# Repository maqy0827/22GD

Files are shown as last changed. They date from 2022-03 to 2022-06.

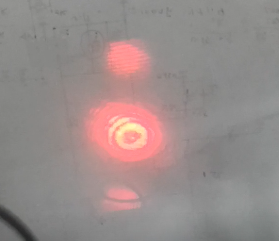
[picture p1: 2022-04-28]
Book/Image/干涉条纹实物图.png

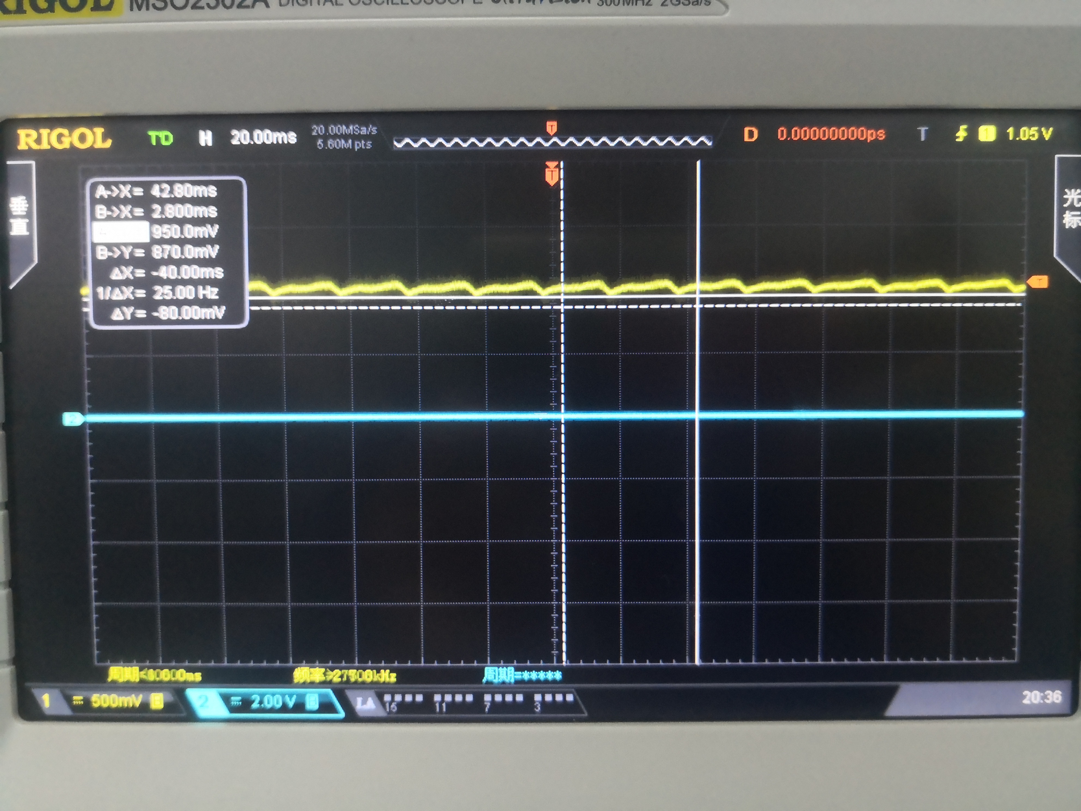
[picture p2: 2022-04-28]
Book/Image/激光光源.jpg

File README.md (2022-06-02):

# 诗云

本项目是来自哈工大威海校区某弱鸡的毕业设计，题目为`基于迈克尔逊干涉仪的位移测量系统`。如希望了解该毕设可以参考[迈克尔逊干涉仪调节实验](https://www.bilibili.com/video/BV1gW411y7Xq)。

# 详细介绍

如果你想看最详细的介绍，我推荐直接看[毕业设计论文](/Book/Thesis/Thesis.pdf)。在写论文的过程中拍摄了实验现象的视频，如有需要可以联系我(邮箱15876781@qq.com，应该不会有吧hhhh)

## 硬件与软件

如果你想复现此项目，你需要准备如下硬件与软件

> 软件
>
> - 绘制电路板使用`Altium Designer 22`
> - 程序设计使用`Keil_v5 (MDK536)`
> - 毕业论文书写~~Texlive2021~~`Word`
> - 推荐使用`VScode`阅读本项目

> 硬件（实物
>
> - 搭建迈克尔逊干涉仪所需的全部光学组件
>> - He-Ne 激光器一个（或其他激光器，但不要使用半导体激光器
>> - 扩束镜一个（或凸透镜 / 凹透镜等可以扩束的光学仪器）
>> - 50/50 分光棱镜（分光片也行但不推荐）
>> - 反光镜两个（均配合二维调整架使用）
>> - 最好有一个光学平台
> - 电路部分所需概要（详情查看原理图 / BOM 表
>> - STM32F103CxT6 最小系统板一块
>> - 12864 OLED 0.96寸 IIC通信 显示屏一块
>> - USB 转串口一个
>> - 电路板所需的其他元器件（包括运放，阻容，光电传感器

## 文件夹

- `.vscode` VScode 配置文件
- `Book` 中期报告与论文
  - `Image` README 与实验记录图片/视频
  - `Midterm` 中期报告
  - `Open` 开题报告
  - `Thesis` 毕业论文与数据处理
- `PCB` 电路板与原理图
  - `Libraries` 原理图库和元件库
  - `22GD` 毕设使用电路板
  - `Test1` 首次测试使用电路板
- `Project` 单片机程序
  - `MDK` **MDK工程入口**
  - 其余文件夹均为程序库

# 感谢

> 感谢以下项目作者
>
> - [dustincys/hithesis: 嗨！thesis！哈尔滨工业大学毕业论文LaTeX模板 (github.com)](https://github.com/dustincys/hithesis)

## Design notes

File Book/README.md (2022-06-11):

# 论文

~~因为 word 对公式的支持实在不咋样，因此毕业论文决定使用`Latex`书写。而从零开始使用`Latex`书写论文有点麻烦（还不如用word）因此，在思考过后决定使用[Dustin](https://github.com/dustincys)大佬完成的哈尔滨工业大学论文开源模板[Hithesis](https://github.com/dustincys/hithesis)（均为`github`网站，如果访问有困难请前往`Gitee`）~~
被老师gank，不能用Latex，老实点用word吧，想办法把word加入git好了

## 开题报告

开题报告于 2021 年 12 月 31 日进行。该报告文件均位于`Open`文件夹中。包含开题报告word版，开题报告pdf版，开题报告使用到的流程图 与 开题报告PPT

## 中期报告

中期报告于 2022 年 4 月 29 日进行，需要完成 70 % 的工作内容和纸质中期报告。该报告所需文件均位于`Minterm`文件夹中。

## 毕业论文

毕业论文于 2022 年 6 月 2 日完成，该报告文件均位于`Thesis`文件夹中， 文件夹内容如下

- `main.m` 处理数据，分析误差
- `Thesis.docx` 毕业论文word版
- `Thesis.vsdx` 论文中使用的框图
- `Thesis.pptx` 验收使用的ppt
- `答辩.pptx` 答辩使用的ppt
- `Liu_2021_J._Phys.__Conf._Ser._2112_012015.pdf` 待翻译的英文文献
- `英文文献翻译.docx` 翻译后的英文文献
- `知网查重报告.pdf` 终稿论文查重报告

验收时PPT内容不怎么重要，你只要保证你ppt，你的毕设内容完整，最好拍一个视频。比如我验收时ppt直接跳过了前边几乎所有，直奔视频了。几乎两三分钟就可以验完一个人，只要做的东西不水就完全没有问题。

- [X] 修改缩进
- [X] 重新画图
- [X] 电阻统一
- [X] 表格字体
- [X] 流程图线粗
- [X] 单位分号
- [X] 结论分号

## 装袋

- [ ] 信息学院本科毕设过程管理记录表
- [ ] 装订好的论文
- [X] 开题报告
- [X] 中期报告
- [ ] 中英译文
- [ ] 指导老师签字的日志

# 数据分析

实验数据分析使用`MATLAB`软件，通过给压电陶瓷加已知电压产生待测位移，在[该网站](http://www.pantpiezo.com/product/3.html)可以找到压电陶瓷的参数 5um/150V，即 33 nm/V，由此可获得位移真值用于和实验结果对比。

# 感谢

> 感谢以下项目作者
>
> - [dustincys/hithesis: 嗨！thesis！哈尔滨工业大学毕业论文LaTeX模板 (github.com)](https://github.com/dustincys/hithesis)

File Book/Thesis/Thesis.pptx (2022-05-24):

## 基于迈克尔逊干涉仪的 位移测量系统

指导老师：任秀云
180220214
马清源

## 研究内容

本毕业设计旨在构造一台通过迈克尔逊干涉仪实现的位移测量系统。
右图为设计的光路图和信号处理流程图。最终的设计目的是能以较高的精度测量输入的位移（理论精度为±λ/8）

## 信号处理框图

## 光电传感器与放大电路

- 光电传感器选择了SFH203P型号光电二极管，右图为放大电路

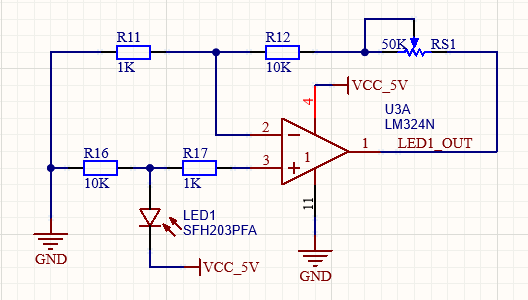
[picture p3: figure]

## 整形电路

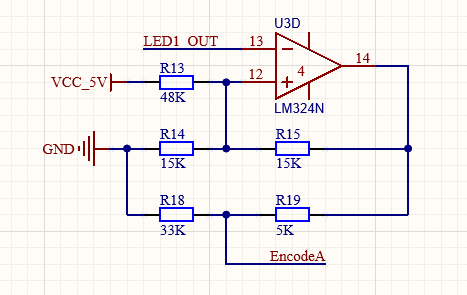
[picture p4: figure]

- 为了计数需要将波形转化为方波，右图为滞回比较器电路图

## 放大和整形电路仿真

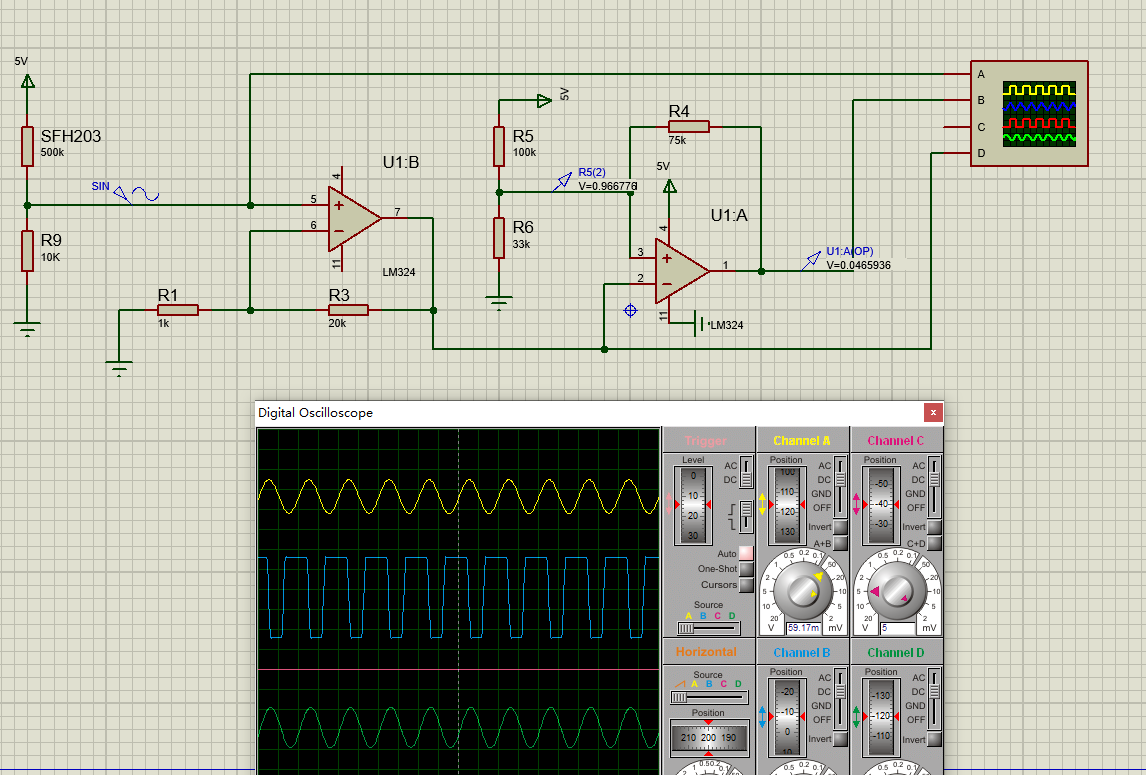
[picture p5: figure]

## 编码器计数原理

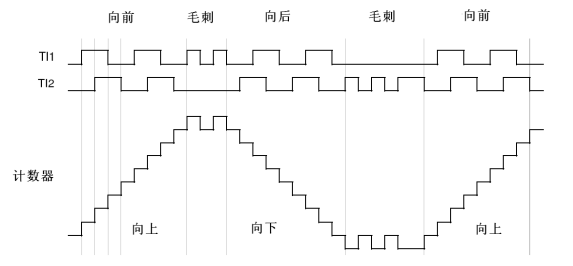
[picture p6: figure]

## 结论和成果展示

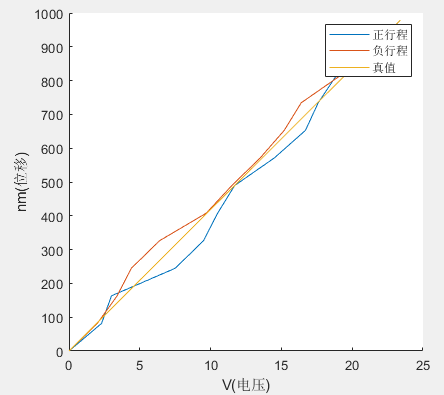
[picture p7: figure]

- 如右图是某一次测量中记录的数据。
- 在多次采集后对误差进行分析可以得到（？）

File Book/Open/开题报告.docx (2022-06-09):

毕业设计（论文）开题报告

题 目： 基于迈克尔逊干涉仪的位移

测量系统

专 业 测控技术与仪器

学 生 马清源

学 号 180220214

班 号 1802202

指导教师 任秀云

日 期 2021/12/29

1．课题背景及研究的目的和意义

科学研究的不断深入，众多领域已步入了微纳米级空间的探索，微位移的测量科学研究的不断深入，众多领域已步入了纳米级空间的探索，位移的测量精度越来越受到重视。无论是航空、航天、大飞机、高铁等大国重器的生产制造，还是芯片、通信光纤、高端医疗设备等民生产品的加工制造，往往都依赖于位移检测的精度，检测精度的高低在优化生产流程、提高产品质量的过程中发挥了至关重要的作用。

高精度的位移测量系统作为机械、仪表、宇航、兵器、工具等产业获得位置高精度的基础，同时也是影响上述产业产品和技术不断进步的制约因素之一。特别是在军事领域，各项武器、仪表等的制作对精度要求极高，因此，拥有高精度的微位移测量技术显得至关重要。在高精度位移测量方面，光干涉计量以其能够精确到波长级的测量优势成为位移测量系统的主要代表。

迈克尔逊干涉仪有着广泛的应用，例如气体折射率测量仪，如图1-1，和液体折射率测量仪，如图1-2。该装置就利用了迈克尔逊干涉仪的原理。

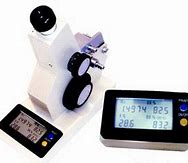
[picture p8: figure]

图1-1 空气折射率测量仪

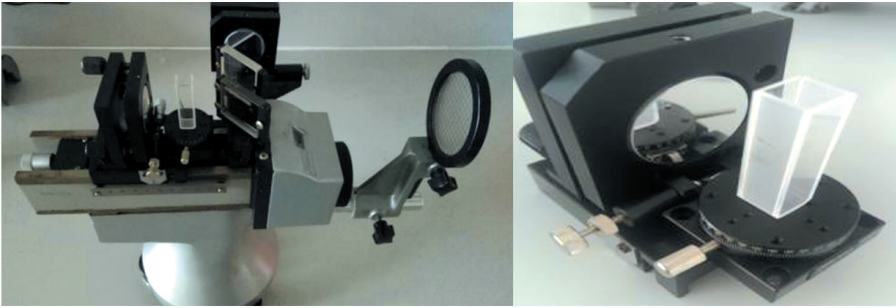
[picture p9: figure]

图1-2 液体折射率测量仪

除此之外，迈克尔逊干涉仪还能用来测量位移量和震动，测量角度或薄透明体的厚度和折射率，测量气体浓度等。迈克尔逊干涉仪的诸多改良也有广泛的用途，例如光纤迈克尔逊干涉仪能够测量混凝土内部应变和地震波加速度。可知迈克尔逊干涉仪的应用非常广泛。

2．国内外在该方向的研究现状及分析

到现在为止，按照测量转换方式的差异，可以将位移测量技术分为，机械测量法，光学测量发和电学测量法。相较于机械测量易受工作环境影响，虽然光学测量法价格较高，但是光学测量法拥有较高的测量精度。下面按照技术路线介绍国内外在微位移测量方面的研究现状和分析。

（1）机械测量技术以扫描探针显微镜为代表，同时也涵盖了机械探针式，根据物体与探针接触方式的不同可将其分为光子扫描隧道显微镜、扫描隧道显微镜、扫描近场光学显微镜和原子力显微镜等几种类型。显微测量技术大都具有很高的精度，但其价格昂贵，且对工作要求苛刻，导致应用范围受限。

（2）采用电学原理的位移测量技术主要有以下几种：电阻式、电感式、差动变压器式和电容式位移传感器。通常的电容式传感器输出阻抗高，负载能力较差，准确度和灵敏度精度受寄生电容，测试环境以及信号源电压的稳定性等方面的影响较大因此使用受到一些局限。目前的电感测微仪存在着测量范围有限、高速动态测量性能差、调节零点不方便且存在零点残余误差以及通用性差等问题，为解决这些问题，相继出现带单片机的电感测微仪，基于虚拟技术的电感测微仪等。

虽然这些非光学测量方法的测量精度可以实现纳米甚至亚纳米级别的测量分辨率，但是米是由光在真空中的传播定义的，所以非光学测量方法需要利用激光干涉仪等光学方法进行比对溯源标定；因此，能够直接溯源的光学测量方法得到了人们更加普遍的关注与重视。

（3）光学测量方法又可以分为许多测量方法，在这里主要介绍单频激光干涉仪，迈克尔逊干涉仪就是最典型的单频激光干涉仪。后来的许多干涉仪都是以它为原型发展改进而来。单频干涉仪以已知的波长为测量基准单位，通过条纹计数来实现位移测量。单频激光干涉仪出现于 20 世纪 60 年代，是激光在计量领域最成功的应用之一。单频激光干涉仪在测量过程中没有加速度的限制，但存在直流漂移，受温度、气压等环境的影响很大，尤其在范围比较大的测量过程中，可能出现较大误差。除了单频激光干涉仪还有光栅干涉仪等，对于光栅干涉法的研究我国起步较早，已将其测量的准确度提高到了纳米与亚纳米的级别。由德国公司推出的双光栅干涉系统测量分辨率也达到了1纳米。

3．研究内容

本次毕业设计旨在构造一台通过迈克尔逊干涉仪实现的微位移测量系统，通过对干涉信号条纹移动的周期数进行计数实现大范围高精度的测量。本次毕业设计内容分为两大部分，迈克尔逊干涉光学系统和信号处理显示部分。这两个部分又可以细分为以下六个设计中的重点，也就是本次毕业设计的研究内容。

1. 激光光源和光感受器的选择与设计
2. 迈克尔逊干涉仪主体的制作
3. 通过压电陶瓷产生已知待测微位移
4. 信号放大辩向与细分电路的搭建
5. 细分辩向后数据的处理和显示电路的搭建
6. 处理和显示程序的编写

4. 拟采取的研究方法和技术路线、进度安排、预期达到的目标

4.1拟采取的研究方法和技术路线

1.迈克尔逊干涉光学系统的制作

根据迈氏干涉仪的原理，采用He-Ne激光器，扩束镜，分光镜和反光镜（定镜和动镜）制作。由 He-Ne 激光器发出的激光经过扩束镜放大后到达立方棱镜，经立方棱镜分光后一部分光束到达定镜，一部分光束到达动镜，两部分光束经过反射后又通过立方棱镜透射到达光屏，两部分光束在光屏（随后应替换为光感受器）汇聚形成干涉圆环。迈克尔逊干涉仪原理如图4-1所示。在移动反射镜1或反射镜2时两束光线的光程差会发生变化，接收器上的干涉圆环也会因此发生变化。

图4-1迈克尔逊干涉仪原理图

2.数据采集和处理

该部分的整体结构图如图4.2所示，该部分细分为滤波放大，细分变相和计数处理显示三部分。

图4.2 数据处理部分流程图

（1）滤波放大部分

直接通过光电传感器获得的干涉信号电压幅值较小，且信噪比也不是很理想，抗干扰的能力较差，并不能直接供系统使用。因此需对其进行处理，因为目前不知道具体的信号强度，暂无法给出合适的放大滤波电路。但目前的设计是先通过输入阻抗高，且放大倍数高的差动放大器后进行滤波。放大器电路图如图4-3所示。通过改变R3的阻值即可调整放大倍数。

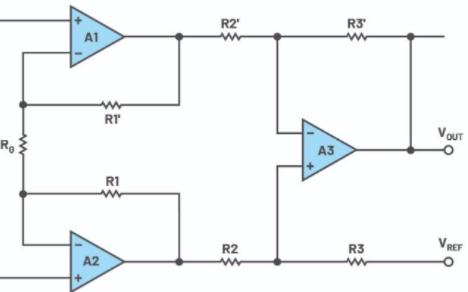
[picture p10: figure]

图4-3 放大器电路图

（2）细分辩向部分

一般辩向需要两路相位差为90°的信号，这里计划在合适的位置放置两个光电传感器以采集两路相位差90°的信号来实现辩向。如图4.4所示。

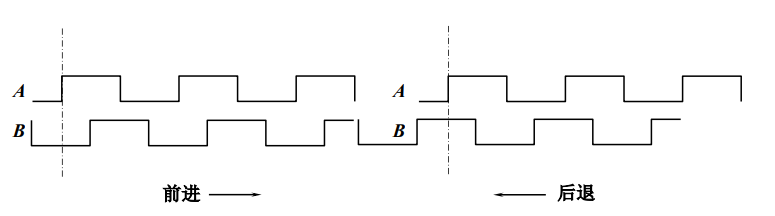
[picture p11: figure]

图4-4 辩向

四细分原理即为，在两路信号产生下降/上升沿时计数，根据此时另一路的电平状态判断此时的运动方向，信号图如图4-5所示.其中A.B两路信号为凉凉相位差为90度的原信号，Uo0，Uo1为计数信号。四细分的参考电路图如图4-6所示。

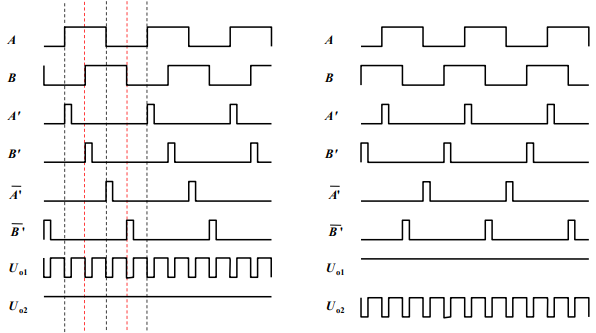
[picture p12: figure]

图4-5 细分信号处理原理

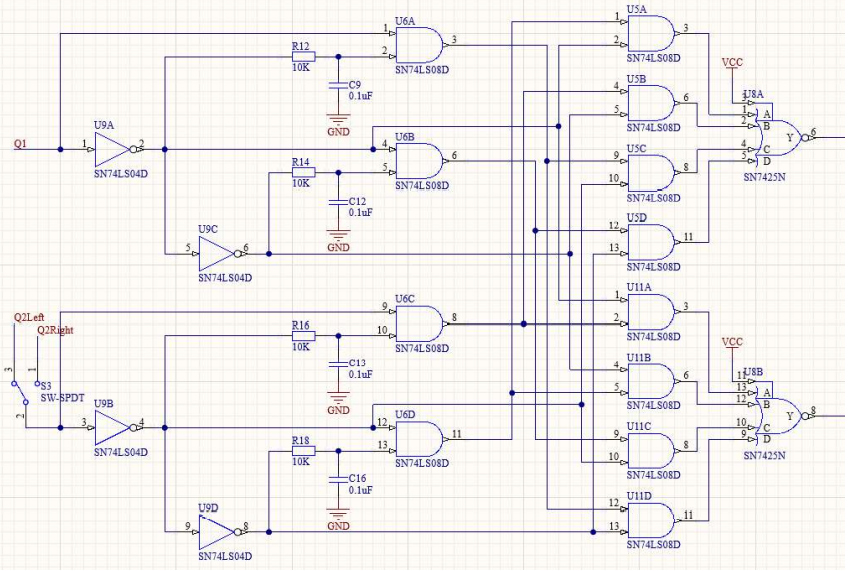
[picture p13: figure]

图4-6 四细分原理示意图

（3）计数显示部分

首先是计数方式的选择，这里有多种方案。一种是使用74LS193计数(同步四位二进制可逆计数器)，这种方式使用芯片多，电路板设计复杂但是成本较低。还有一种是直接使用单片机中的计数器，例如stm32单片机就有可以正交解码的计数器1和计数器8。这种方案的优点是使用芯片很少，电路板可以做的较小，但成本较高（有此功能的单片机价格较高）。

显示可以选择OLED或数码管，为了节省引脚同时能够显示更多信息我选择使用12864，这是一种使用I2C通信或SPI通信的显示屏。有128*64个像素点，能够留出充足的显示余量，而且美观的同时价格也不贵。如图4-7即为使用SPI通信的一种12864。

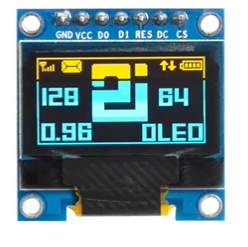
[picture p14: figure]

图4-7 双色12864显示屏

4.2进度安排

3月1日 – 3月15日：选择光电传感器并搭建此部分电路并测试

3月16日 – 4月2日：信号处理部分电路板的绘制和程序的编写

4月3日 – 4月18日：迈克尔逊干涉仪搭建并结合信号处理部分测试

4月19日 – 4月28日：解决过程中出现的错误和漏洞

中期答辩

4月29日 – 5月15日：重新绘制可靠性更高的电路板

5月16日 – 5月31日：整理实验资料，书写毕业设计论文

结题验收

6月1日 – 6月15日： 书写毕业设计论文

毕设答辩

4.3预期达到的目标

中期验收前完成迈克尔逊干涉系统的搭建，完成可以使用的数据采集电路，确保电路可以使用，程序合理简洁，测量结果没有较大误差。

结题验收前完成整套系统的设计，首先确保仪器的基础功能的可靠性，即可以正常准确的测量位移。其次尽量保证仪器的小型化，和易操作性。

5．课题已具备和所需的条件

开题所需的仿真和程序设计软件（keil，Altium Designer，proteus等）；

已搜集多篇迈克尔逊干涉仪和微位移测量相关文献；

指导老师的耐心指导。

6．研究过程中可能遇到的困难和问题，解决的措施

迈克尔逊干涉系统的搭建中可能遇到不出现干涉条纹，或是在经过人为干扰后不出现干涉条纹的情况。解决措施是仔细排查搭建的迈克尔逊干涉仪，确保没有出现错误，在该过程中可能会对迈克尔逊干涉仪部分做反复的调整。

处理光电传感器的传出信号部分电路可能出现不正常工作，或是在动镜移动过快时采集信号频率较高导致计数减少等问题。解决措施是根据遇到错误的实际情况来随机应变的解决，解决方法包括但不限于重新设计处理电路，换用通带频率更高的运算放大器或是更改信号处理方法。

7．参考文献

[1]王斌. 差动式迈克尔逊干涉纳米位移测量方法研究[D].浙江理工大学，2015

[2]周森. 基于共线光外差的微位移测量系统研究与应用[D].中北大学，2021

[3]刘建静. 迈克尔孙干涉仪的应用研究[J].物理通报，2015

[4]王冬. 用于微位移测量的迈克尔逊激光干涉仪综述[J].计量学报，2021

[5]陈泽远. 基于电容法的微位移测量系统[D].湖北工业大学，2020

[6]李褀. 基于迈克尔逊干涉的风速测量系统的设计[D].南京信息工程大学，2018

[7]林澎,孙荣敏. 基于迈克尔逊干涉仪的阵列角锥棱镜位移测量系统的研究[J].轻工科技，2016,32(11):49-50+59.
[8]乔亮. 迈克尔逊干涉实验的仿真研究[J].重庆三峡学院学报，2015,31(03):50-52

[9]赵宏波. 光栅干涉型微位移测量系统关键技术研究[D].中北大学，2020.

[10]金锋,卢杨,王文松,张玉平. 光栅四倍频细分电路模块的分析与设计[J].北京理工大学学报，2006(12):1073-1076.

[11]Pengfei Li,Haitao Yan,Haojie Zhang. Highly sensitive liquid level sensor based on an optical fiber Michelson interferometer with core-offset structure[J]. Optik,2018

[12]Wentao Zhang,Yulin Wang,Hao Du,Qilin Zeng,Xianming Xiong. High-precision displacement measurement model for the grating interferometer system[J]. Optical Engineering,2020

[13]Ghazinoory S, Divsalar A, Soofi A S. A new definition and framework for the development of a national technology strategy: The case of nanotechnology for Iran[J]. Technological Forecasting and Social Change,2009,76(6):835-848

[14]Macoubrie J. Nanotechnology: public concerns, reasoning and trust in government[J]. Public

Understanding of Science,2006,15(2): 221-241.

[15] Radhakrishnan V. Effect of stylus radius on the roughness values measured with tracing stylus instruments[J]. Wear, 1970, 16(5): 325-335.

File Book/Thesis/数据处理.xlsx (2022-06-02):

第一组
 | 0 | 1 | 2 | 3 | 4 | 5 | 6 | 7 | 8 | 9 | 10 | 11 | 12
正行程 | 0 | 2.3 | 3 | 7.5 | 9.5 | 10.5 | 11.7 | 14.5 | 16.7 | 17.6 | 18.9 | 21.7 | 23.4
负行程 | 0 | 2 | 3.4 | 4.4 | 6.4 | 9.7 | 11.5 | 13.5 | 15.2 | 16.4 | 19.2 | 21.5 | 23.4
理论值 | 0 | 79.1 | 158.2 | 237.3 | 316.4 | 395.5 | 474.6 | 553.7 | 632.8 | 711.9 | 791 | 870.1 | 949.2
正 | 0 | 76.66666667 | 100 | 250 | 316.6666667 | 350 | 390 | 483.3333333 | 556.6666667 | 586.6666667 | 630 | 723.3333333 | 780
负 | 0 | 66.66666667 | 113.3333333 | 146.6666667 | 213.3333333 | 323.3333333 | 383.3333333 | 450 | 506.6666667 | 546.6666667 | 640 | 716.6666667 | 780
正行程误差 |  | 2.433333333 | 58.2 | -12.7 | -0.2666666667 | 45.5 | 84.6 | 70.36666667 | 76.13333333 | 125.2333333 | 161 | 146.7666667 | 169.2
负行程误差 |  | 12.43333333 | 44.86666667 | 90.63333333 | 103.0666667 | 72.16666667 | 91.26666667 | 103.7 | 126.1333333 | 165.2333333 | 151 | 153.4333333 | 169.2
 |  | 0.03076274758 | 0.3678887484 | -0.05351875263 | -0.0008428150021 | 0.1150442478 | 0.1782553729 | 0.1270844621 | 0.1203118416 | 0.1759142202 | 0.203539823 | 0.1686779297 | 0.1782553729
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

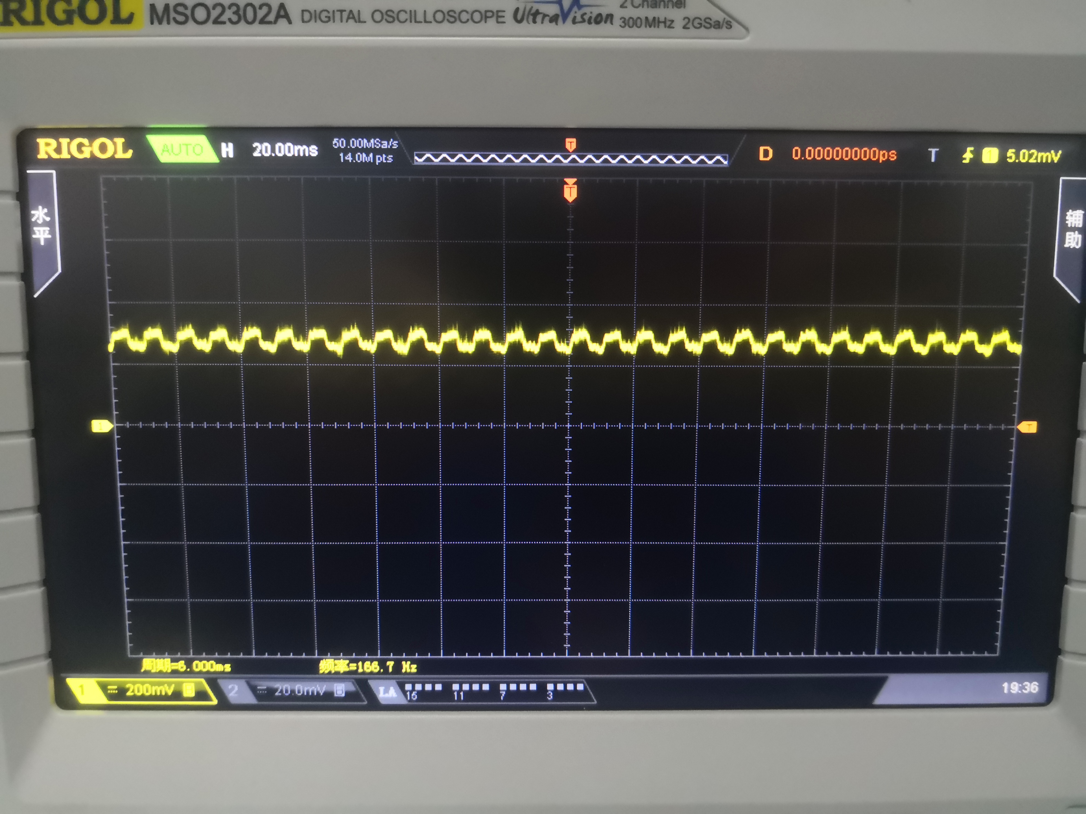
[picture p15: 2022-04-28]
Book/Image/并联104自然光.jpg

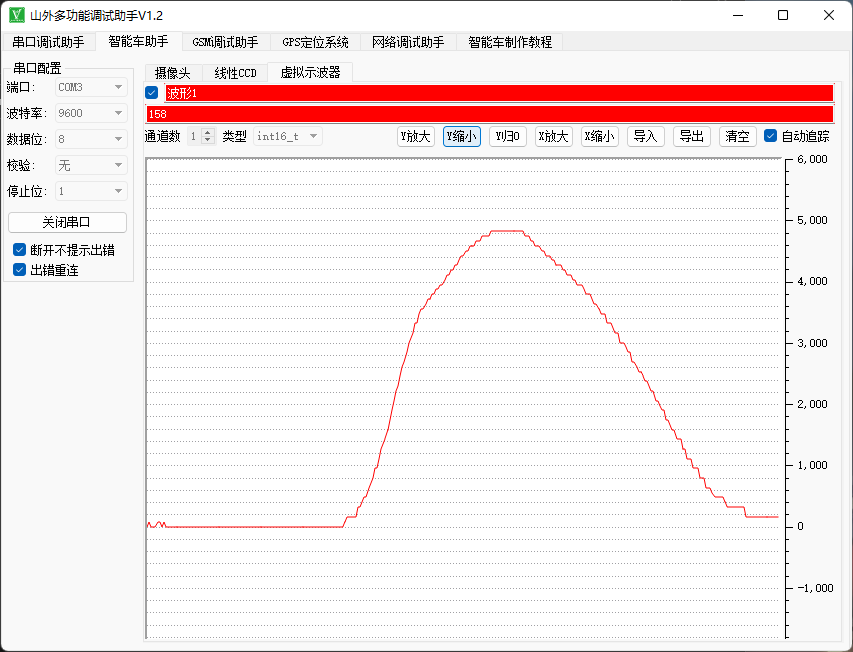
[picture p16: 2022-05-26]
Book/Image/0-110v-0.png

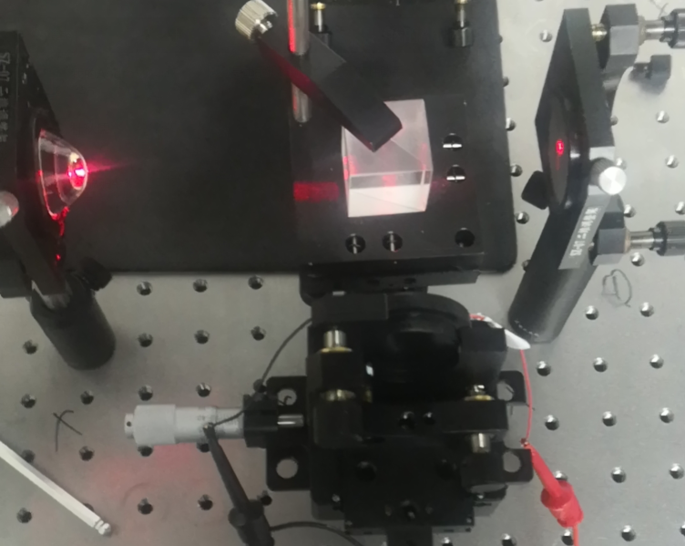
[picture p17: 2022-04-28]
Book/Image/干涉仪实物图.png

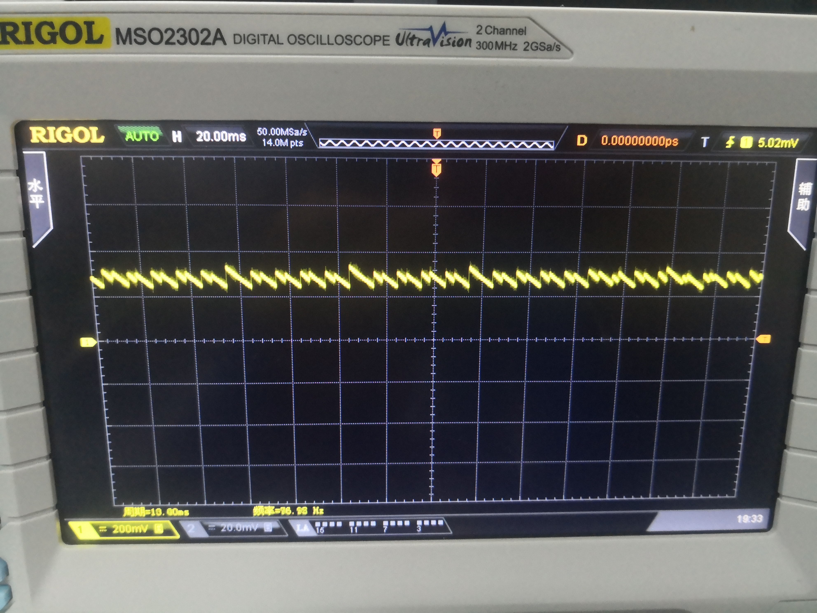
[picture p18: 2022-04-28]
Book/Image/并联106自然光.jpg

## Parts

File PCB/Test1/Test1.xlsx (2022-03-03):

Comment | Description | Designator | Footprint | LibRef | Quantity
Cap Semi | Capacitor (Semiconductor SIM Model) | C1 | C1206 | Cap Semi | 1
Cap Semi | Capacitor (Semiconductor SIM Model) | C2, C3 | CAP-TH_L5.5-W3.0-P5.00-D0.6 | Cap Semi | 2
SFH203PFA |  | LED1 | LED-TH_BD5.9-P2.54-FD | SFH203PFA | 1
5V | Header, 3-Pin | P1 | HDR1X3 | Header 3 | 1
GND | Header, 3-Pin | P2 | HDR1X3 | Header 3 | 1
O1T | Header, 2-Pin | P3 | HDR1X2 | Header 2 | 1
TM | Header, 2-Pin | P4 | HDR1X2 | Header 2 | 1
CMIN | Header, 2-Pin | P5 | HDR1X2 | Header 2 | 1
CM | Header, 2-Pin | P6, P7, P8 | HDR1X2 | Header 2 | 3
Res2 | Resistor | R1, R2, R3, R4, R6, R7, R8, R9, R10, R12, R13, R14, R15 | AXIAL-0.4 | Res2 | 13
RPot | Potentiometer | R5, R11 | RES-ADJ-TH_3P-L10.0-W10.0-P2.50-L | RPot | 2
2DU6 |  | S1, S2 | 2DU6PERSONAL | 2DU6 | 2
LM324N |  | U1 | DIP-14_L19.4-W6.4-P2.54-LS7.6-BL | LM324N | 1

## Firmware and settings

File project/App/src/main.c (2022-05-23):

/*
 * @Author: 诗云
 * @Date: 2022-02-28 10:22:38
 * @FilePath: \22GDproject\Project\App\src\main.c
 * @Description: 主函数
 *
 */
#include "stm32f10x.h"
#include "oled.h"
#include "delay.h"
#include "measure.h"
#include "stdio.h"

//重定向 printf 函数
int fputc(int ch, FILE *f)
{
	while (!(USART1->SR & USART_FLAG_TXE));
	USART1->DR = (uint8_t)ch;
	return ch;
}


//激光波长，单位0.1nm
#define Laser_WaveLength (632/2)

int main(void)
{
	uint8_t mode = 2;
	int ans = 0,N = 0;
	delay_init();	//初始化延时函数
	OLED_init();	//初始化OLED
	measure_init();//初始化测量所需
	//testPWM_init();

	while(1)
	{
		OLED_clear();

		//等待 SW1 被按下，开始
		while(!SW1)
		{
			OLED_show8x16string(0,0,"Waiting...");
			delay_ms(50);
		}

		//失能定时器，更改显示内容
		TIM_Cmd(TIM2,DISABLE);
		TIM_SetCounter(TIM2,0);
		OLED_clear();
		OLED_show8x16string(0,0,"Sft:");
		OLED_show8x16string(0,2,"Ctr:");
		OLED_show8x16string(0,4,"L1O:");
		TIM_Cmd(TIM2,ENABLE);

		//测量中显示
		while(!SW2)
		{
			//SW3 计数模式转换
			if(SW3)
			{
				change_mode(&mode);
				while(SW3);
			}

			//获取计数值并计算位移
			N = (int16_t)TIM_GetCounter(TIM2);
			if(mode == 1)
			{
				ans = N * Laser_WaveLength;
			}
			else if(mode == 2)
			{
				ans = N * (Laser_WaveLength/4);
			}

			//显示位移和调试信息
			OLED_show8x16number(32,0,ans);
			OLED_show8x16number(32,2,N);
			OLED_show8x16number(32,4,ADC_get(LED1_OUT,20));
			OLED_show8x16number(32,6,ADC_get(LED2_OUT,20));
			OLED_show8x16number(0,6,mode);
			delay_ms(20);
			//printf("ans=%dnm\n",ans);
			datstx(ans);
		}
		while(!SW4)
		{

		}
		delay_ms(10);
	}

	return 0;
}

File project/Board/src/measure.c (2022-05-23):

#include "measure.h"

//转换模式
void change_mode(uint8_t* mode)
{
	TIM_DeInit(TIM2);
	if(*mode == 1)
	{
		TIM_EncoderInterfaceConfig(TIM2,TIM_EncoderMode_TI12,TIM_ICPolarity_Rising,TIM_ICPolarity_Rising);
		*mode = 2;
	}
	else if(*mode == 2)
	{
		TIM_ETRClockMode2Config(TIM2,TIM_ExtTRGPSC_OFF,TIM_ExtTRGPolarity_NonInverted,0);
		*mode = 1;
	}
	TIM_SetCounter(TIM2,0);
	TIM_Cmd(TIM2, ENABLE);
	return;
}

//测量初始化
void measure_init(void)
{
	//初始化 PB3 - PB9 按键输入引脚，PC13 LED 引脚
	RCC_APB2PeriphClockCmd(RCC_APB2Periph_GPIOA,ENABLE);
	RCC_APB2PeriphClockCmd(RCC_APB2Periph_GPIOB,ENABLE);
	RCC_APB2PeriphClockCmd(RCC_APB2Periph_GPIOC,ENABLE);

	GPIO_InitTypeDef GPIO_InitStructure;
	GPIO_InitStructure.GPIO_Pin = 0x01FC;					//PB3 - PB9
	GPIO_InitStructure.GPIO_Speed = GPIO_Speed_50MHz;		//50MHz 输出速度
	GPIO_InitStructure.GPIO_Mode = GPIO_Mode_IN_FLOATING;	//浮空输入，外部下拉
	GPIO_Init(GPIOB,&GPIO_InitStructure);

	GPIO_InitStructure.GPIO_Pin = GPIO_Pin_15;				//PA15
	GPIO_Init(GPIOA,&GPIO_InitStructure);

	//核心板 LED引脚初始化
	GPIO_InitStructure.GPIO_Pin = GPIO_Pin_13;
	GPIO_InitStructure.GPIO_Mode = GPIO_Mode_Out_OD;		//开漏输出
	GPIO_Init(GPIOC,&GPIO_InitStructure);


	//TIM2 设定 输入捕获计数，输入端口 PA0 ，正交解码计数时输入 PA0 PA1
	RCC_APB2PeriphClockCmd(RCC_APB2Periph_GPIOA,ENABLE);	//使能 GPIOA 时钟
	RCC_APB1PeriphClockCmd(RCC_APB1Periph_TIM2,ENABLE);		//使能TIM2时钟

	GPIO_InitStructure.GPIO_Pin = GPIO_Pin_0|GPIO_Pin_1;	//PA0
	GPIO_InitStructure.GPIO_Speed = GPIO_Speed_50MHz;		//50MHz 输出速度
	GPIO_InitStructure.GPIO_Mode = GPIO_Mode_IN_FLOATING;	//浮空输入
	GPIO_Init(GPIOA,&GPIO_InitStructure);

	TIM_DeInit(TIM2);
	TIM_TimeBaseInitTypeDef  TIM_TimeBaseStructure;
	TIM_TimeBaseStructure.TIM_Period = 0xFFFF;				//重装载寄存器
	TIM_TimeBaseStructure.TIM_Prescaler = 0;				//预分频系数
	TIM_TimeBaseStructure.TIM_ClockDivision = TIM_CKD_DIV1;	//时钟分割
	TIM_TimeBaseStructure.TIM_CounterMode = TIM_CounterMode_Up;//向上计数
	TIM_TimeBaseStructure.TIM_RepetitionCounter = 0;		//重复计数次数
	TIM_TimeBaseInit(TIM2,&TIM_TimeBaseStructure);

	//选择正交解码/直接计数
	//TIM_ETRClockMode2Config(TIM2,TIM_ExtTRGPSC_OFF,TIM_ExtTRGPolarity_NonInverted,0);
	TIM_EncoderInterfaceConfig(TIM2,TIM_EncoderMode_TI12,TIM_ICPolarity_Rising,TIM_ICPolarity_Rising);

	TIM_SetCounter(TIM2,0);
	TIM_Cmd(TIM2, ENABLE);


	//初始化 ADC1 IN2345 用于提高测量精度
	RCC_APB2PeriphClockCmd(RCC_APB2Periph_GPIOA,ENABLE);
	RCC_APB2PeriphClockCmd(RCC_APB2Periph_ADC1,ENABLE);

	GPIO_InitStructure.GPIO_Pin = GPIO_Pin_4|GPIO_Pin_5;	//PA4 - PA5
	GPIO_InitStructure.GPIO_Speed = GPIO_Speed_50MHz;		//50MHz 输出速度
	GPIO_InitStructure.GPIO_Mode = GPIO_Mode_AIN;			//模拟输入
	GPIO_Init(GPIOA,&GPIO_InitStructure);

	ADC_InitTypeDef ADC_InitStructure;
	ADC_InitStructure.ADC_Mode = ADC_Mode_Independent;		//两 ADC 互相独立
	ADC_InitStructure.ADC_ScanConvMode = DISABLE;			//扫描转换模式不开
	ADC_InitStructure.ADC_ContinuousConvMode = DISABLE;		//连续转换模式不开
	ADC_InitStructure.ADC_ExternalTrigConv = ADC_ExternalTrigConv_None;//不适用外部触发
	ADC_InitStructure.ADC_DataAlign = ADC_DataAlign_Right;	//数据对齐方式右对齐
	ADC_InitStructure.ADC_NbrOfChannel = 1;					//转换通道数量1
	ADC_Init(ADC1,&ADC_InitStructure);

	RCC_ADCCLKConfig(RCC_PCLK2_Div8);						//时钟分频 8(9 MHz)
	ADC_Cmd(ADC1,ENABLE);
	ADC_ResetCalibration(ADC1);
	while(ADC_GetResetCalibrationStatus(ADC1));
	ADC_StartCalibration(ADC1);				//校准
	while(ADC_GetCalibrationStatus(ADC1));	//等待校准完成


	//初始化串口1，不使用串口
	RCC_APB2PeriphClockCmd(RCC_APB2Periph_USART1|RCC_APB2Periph_GPIOA, ENABLE);

	//初始化 PA9 PA10
	GPIO_InitStructure.GPIO_Pin = GPIO_Pin_9;
	GPIO_InitStructure.GPIO_Speed = GPIO_Speed_50MHz;
	GPIO_InitStructure.GPIO_Mode = GPIO_Mode_AF_PP;
	GPIO_Init(GPIOA, &GPIO_InitStructure);

	GPIO_InitStructure.GPIO_Pin = GPIO_Pin_10;
	GPIO_InitStructure.GPIO_Mode = GPIO_Mode_IN_FLOATING;
	GPIO_Init(GPIOA, &GPIO_InitStructure);

	USART_InitTypeDef USART_InitStructure;
	USART_InitStructure.USART_BaudRate = 9600;
	USART_InitStructure.USART_WordLength = USART_WordLength_8b;	//数据长度 8 位
	USART_InitStructure.USART_StopBits = USART_StopBits_1;		//停止位1
	USART_InitStructure.USART_Parity = USART_Parity_No;			//无校验位
	USART_InitStructure.USART_HardwareFlowControl = USART_HardwareFlowControl_None;
	USART_InitStructure.USART_Mode = USART_Mode_Rx | USART_Mode_Tx;//同时收发
	USART_Init(USART1, &USART_InitStructure);
	USART_Cmd(USART1, ENABLE);

	return;
}

//使用 TIM3 输出两路相位差 90 度的 PWM 测试用函数
void testPWM_init(int period)
{
	//TIM3 设定比较输出，输出端口 PA6 PA7
	RCC_APB1PeriphClockCmd(RCC_APB1Periph_TIM3,ENABLE);		//使能 TIM3 时钟
	RCC_APB2PeriphClockCmd(RCC_APB2Periph_GPIOA,ENABLE);	//使能 GPIOA 时钟
	RCC_APB2PeriphClockCmd(RCC_APB2Periph_AFIO,ENABLE);		//使能复用时钟

	GPIO_InitTypeDef GPIO_InitStructure;
	GPIO_InitStructure.GPIO_Pin = GPIO_Pin_6|GPIO_Pin_7;	//PA6 PA7
	GPIO_InitStructure.GPIO_Speed = GPIO_Speed_50MHz;		//50MHz 输出速度
	GPIO_InitStructure.GPIO_Mode = GPIO_Mode_AF_PP;			//服用推挽输出
	GPIO_Init(GPIOA,&GPIO_InitStructure);

	TIM_DeInit(TIM3);
	TIM_TimeBaseInitTypeDef  TIM_TimeBaseStructure;
	TIM_TimeBaseStructure.TIM_Period = period;				//重装载寄存器
	TIM_TimeBaseStructure.TIM_Prescaler = 2699;				//预分频系数
	TIM_TimeBaseStructure.TIM_ClockDivision = TIM_CKD_DIV4;	//时钟分割
	TIM_TimeBaseStructure.TIM_CounterMode = TIM_CounterMode_Up;//向上计数
	TIM_TimeBaseStructure.TIM_RepetitionCounter = 0;		//重复计数次数
	TIM_TimeBaseInit(TIM3,&TIM_TimeBaseStructure);

	TIM_OCInitTypeDef TIM_OCInitStrue;
	TIM_OCInitStrue.TIM_OCMode = TIM_OCMode_Toggle;			//CNT = CCR 时反转电平
	TIM_OCInitStrue.TIM_Pulse = 0;
	TIM_OCInitStrue.TIM_OCPolarity = TIM_OCPolarity_High;	//有效输出高电平
	TIM_OCInitStrue.TIM_OutputState = TIM_OutputState_Enable;//输出使能
	TIM_OC1Init(TIM3,&TIM_OCInitStrue);
	TIM_OC2Init(TIM3,&TIM_OCInitStrue);

	TIM_OC1PreloadConfig(TIM3,TIM_OCPreload_Enable);		//使能预装载寄存器
	TIM_OC2PreloadConfig(TIM3,TIM_OCPreload_Enable);

	//产生两路相位差 90 度的信号
	TIM_SetCompare1(TIM3,period/4);
	TIM_SetCompare2(TIM3,period/4*3);

	TIM_Cmd(TIM3,ENABLE);
	return;
}

void USART1send(uint8_t ch)
{
	while (!(USART1->SR & USART_FLAG_TXE));
	USART1->DR = (uint8_t)ch;
	return;
}

void datstx(uint16_t ans)
{
	USART1send(0x03);
	USART1send(0xfc);
	USART1send(ans &0x00FF);
	USART1send(ans >>8);
	USART1send(0xfc);
	USART1send(0x03);
	return;
}

uint16_t ADC_get(uint8_t channel,uint8_t time)
{
	int ans = 0;

	//设置采集通道和周期
	ADC_RegularChannelConfig(ADC1,channel,1,ADC_SampleTime_71Cycles5);
	uint8_t a = time;

	//进行 time 次采集
	while(a --)
	{
		ADC_SoftwareStartConvCmd(ADC1,ENABLE);
		while(!ADC_GetFlagStatus(ADC1,ADC_FLAG_EOC));
		ans += (int)ADC_GetConversionValue(ADC1);
	}
	ans /= time;
	ans = (ans * 3300)>>12;
	return ans;
}

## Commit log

2022-02-28 添加gitignore，许可证，README文件
2022-02-28 C6T6空白工程
2022-02-28 配置VScode
2022-03-03 丰富了OLED显示函数
2022-03-03 完成第一版PCB
    [PCB.PcbDoc, PcbLib.PcbLib, Schlib.SchLib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]
2022-03-04 增加C6T6转接板库
    [PcbLib.PcbLib, Schlib.SchLib, Sheet.SchDoc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]
2022-03-04 测试外部计数功能
2022-03-08 功能性测试完成
    [Test1.PrjPcb]
2022-03-09 测试ADC
    [22GD.PrjPcb, PCB.PcbDoc, Sheet.SchDoc]
2022-03-14 原理图提交
    [22GD.PrjPcb, Sheet.SchDoc]
2022-03-15 画PCB第1天
    [22GD.PrjPcb, PCB.PcbDoc, Sheet.SchDoc]
2022-03-16 PCB第1版完成
    [22GD.PrjPcb, PCB.PcbDoc, Sheet.SchDoc]
2022-03-17 加入固定孔
    [PCB.PcbDoc]
2022-03-18 增加控制函数
2022-03-24 写主程序逻辑（云
2022-03-29 更新README
2022-04-03 修改cpp配置
2022-04-03 提交中期报告模板
    [hithesisart.cfg]
2022-04-04 修改格式
    [hithesisart.cfg]
2022-04-14 更换毕设模板为word
    [hithesisart.cfg]
2022-04-14 更新ignore
2022-04-16 第2板PCB - 删除无用电路 - 更换电阻为直插件 - 增加测试点 - 更改固定孔位置
    [22GD.PrjPcb, PCB.PcbDoc, Sheet.SchDoc]
2022-04-27 加入开题报告
2022-04-27 中期报告V1
2022-04-28 中期报告V2
2022-05-08 计数测试
2022-05-23 加入串口
2022-05-24 毕业论文V0.1
2022-05-26 数据处理V1
    [数据处理.xlsx]
2022-05-28 PPT更新V1.0
2022-05-28 毕业论文V0.2 第二章完成 第三章开头
2022-05-31 毕业论文V0.3 第一章开头 第三章一半
2022-05-31 毕业论文V0.4 除了第一章都写完了
2022-06-01 毕业论文V0.5 初稿完成
    [数据处理.xlsx]
2022-06-01 matlab数据处理
2022-06-02 毕业论文V1.0 终稿 已查重
    [数据处理.xlsx]
2022-06-02 添加查重报告等pdf文件
2022-06-08 毕业论文V1.1 重绘部分图片 修改部分格式 添加答辩PPT
2022-06-09 修订部分格式
2022-06-11 终于可以不受这气了
